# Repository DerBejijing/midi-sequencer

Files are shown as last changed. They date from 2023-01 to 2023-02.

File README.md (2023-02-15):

# midi-sequencer
midi sequencer firmware for raspberry pico (moog 960-sequencer inspired)  
Inspired by moog, but turned out to look more like the MAQ16 lul  

## about  
This is a midi step sequencer inspired by the 960 made by moog in the 70s.
Since getting to know it, I have always loved the moog IIIp modular synthesizer, which is why I decided to build my own version of the sequencer complement B.
The cabinet holds two of those modules plus an additional "half-height" (actually about 60%) row, like the original one.
During the building process, I diverged from my original design over and over again, and in the end, I even had to borrow some parts from the other sequencer in the cabinet.  

## features  
- 3 rows with eight steps  
- rows can be played in parallel or serial  
- the lengths of all rows can be adjusted independently  
- a variable amount of ratcheting can be set per step  
- speed is adjustable  
- all values are sent over midi (channels 0-3 in parallel mode, 0 in serial)  

<br/>

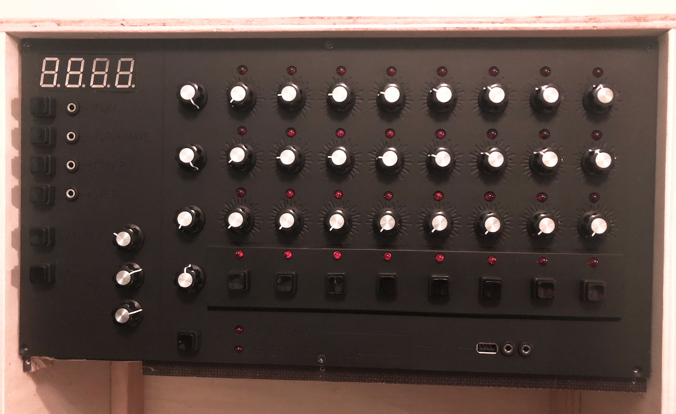
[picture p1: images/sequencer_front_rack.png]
  

TODO-List:  
---> add serial communication to controller  
---> find out how to make markdown add padding to a list next to an image >:(

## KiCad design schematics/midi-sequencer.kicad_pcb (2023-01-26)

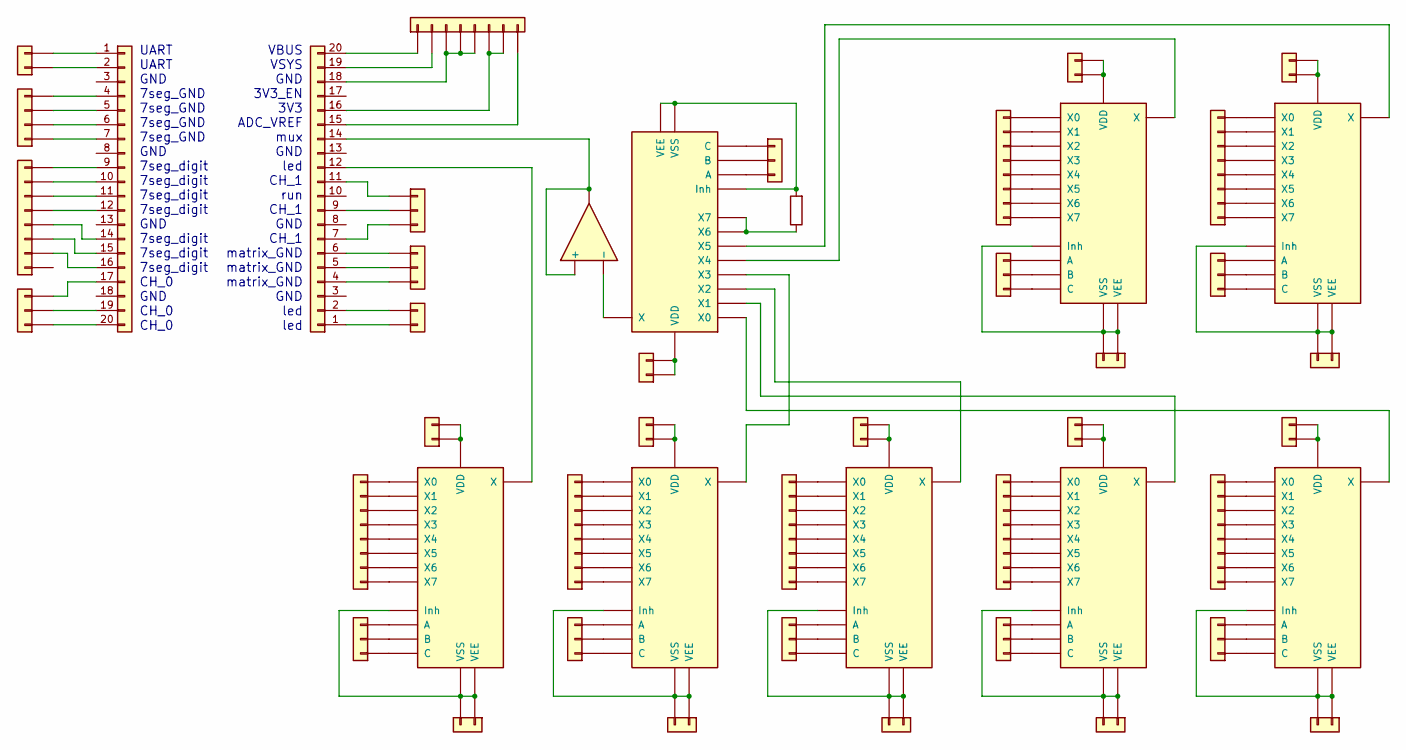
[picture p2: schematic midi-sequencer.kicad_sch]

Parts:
J1, J11, J12, J14, J17, J18, J19, J23, J24, J29, J30, J31, J32, J37, J38, J39, J40: Conn_01x02; PinHeader_1x02_P2.54mm_Vertical
J2: Conn_01x04; PinHeader_1x04_P2.54mm_Vertical
J3, J7, J13, J15, J21, J25, J27, J33, J35: Conn_01x08; PinHeader_1x08_P2.54mm_Vertical
J4, J8, J9, J10, J16, J20, J22, J26, J28, J34, J36: Conn_01x03; PinHeader_1x03_P2.54mm_Vertical
J5, J6: Conn_01x20; PinHeader_1x20_P2.54mm_Vertical
R1: R; R_Box_L13.0mm_W4.0mm_P9.00mm
U1, U3, U4, U5, U6, U7, U8, U9: 4051; DIP-16_W7.62mm_Socket
U2: OPA1622; DIP-14_W7.62mm_Socket

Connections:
unnamed: J1.1, J5.2
unnamed: J1.2, J5.1
unnamed: J2.1, J5.7
unnamed: J2.2, J5.6
unnamed: J2.3, J5.5
unnamed: J2.4, J5.4
unnamed: J3.2, J5.16
unnamed: J3.3, J5.15
unnamed: J3.4, J5.14
unnamed: J3.5, J5.12
unnamed: J3.6, J5.11
unnamed: J3.7, J5.10
unnamed: J3.8, J5.9
unnamed: J4.1, J5.20
unnamed: J4.2, J5.19
unnamed: J4.3, J5.17
unnamed: J6.7, J9.3
unnamed: J6.12, U1.3 (X)
unnamed: J7.1, U1.4 (X7)
unnamed: J7.2, U1.2 (X6)
unnamed: J7.3, U1.5 (X5)
unnamed: J7.4, U1.1 (X4)
unnamed: J7.5, U1.12 (X3)
unnamed: J7.6, U1.15 (X2)
unnamed: J7.7, U1.14 (X1)
unnamed: J7.8, U1.13 (X0)
unnamed: J8.1, U1.9 (C)
unnamed: J8.2, U1.10 (B)
unnamed: J8.3, U1.11 (A)
unnamed: J6.11, J9.1
unnamed: J6.9, J9.2
unnamed: J6.6, J10.1
unnamed: J6.5, J10.2
unnamed: J6.4, J10.3
unnamed: J6.2, J11.1
unnamed: J6.1, J11.2
unnamed: J12.1, J12.2, U1.16 (VDD)
unnamed: J6.20, J13.1
unnamed: J6.19, J13.2
unnamed: J6.18, J13.3, J13.4, J13.5
unnamed: J6.16, J13.6, J13.7
unnamed: J6.15, J13.8
unnamed: J14.1, J14.2, U1.6 (Inh), U1.7 (VEE), U1.8 (VSS)
unnamed: J15.1, U4.4 (X7)
unnamed: J15.2, U4.2 (X6)
unnamed: J15.3, U4.5 (X5)
unnamed: J15.4, U4.1 (X4)
unnamed: J15.5, U4.12 (X3)
unnamed: J15.6, U4.15 (X2)
unnamed: J15.7, U4.14 (X1)
unnamed: J15.8, U4.13 (X0)
unnamed: J16.1, U4.9 (C)
unnamed: J16.2, U4.10 (B)
unnamed: J16.3, U4.11 (A)
unnamed: J17.1, J17.2, U3.16 (VDD)
unnamed: J18.1, J18.2, U4.16 (VDD)
unnamed: J19.1, J19.2, U4.6 (Inh), U4.7 (VEE), U4.8 (VSS)
unnamed: J20.1, U3.9 (C)
unnamed: J20.2, U3.10 (B)
unnamed: J20.3, U3.11 (A)
unnamed: J21.1, U5.4 (X7)
unnamed: J21.2, U5.2 (X6)
unnamed: J21.3, U5.5 (X5)
unnamed: J21.4, U5.1 (X4)
unnamed: J21.5, U5.12 (X3)
unnamed: J21.6, U5.15 (X2)
unnamed: J21.7, U5.14 (X1)
unnamed: J21.8, U5.13 (X0)
unnamed: J22.1, U5.9 (C)
unnamed: J22.2, U5.10 (B)
unnamed: J22.3, U5.11 (A)
unnamed: J23.1, J23.2, U5.16 (VDD)
unnamed: J24.1, J24.2, U5.6 (Inh), U5.7 (VEE), U5.8 (VSS)
unnamed: J25.1, U6.4 (X7)
unnamed: J25.2, U6.2 (X6)
unnamed: J25.3, U6.5 (X5)
unnamed: J25.4, U6.1 (X4)
unnamed: J25.5, U6.12 (X3)
unnamed: J25.6, U6.15 (X2)
unnamed: J25.7, U6.14 (X1)
unnamed: J25.8, U6.13 (X0)
unnamed: J26.1, U6.9 (C)
unnamed: J26.2, U6.10 (B)
unnamed: J26.3, U6.11 (A)
unnamed: J27.1, U7.4 (X7)
unnamed: J27.2, U7.2 (X6)
unnamed: J27.3, U7.5 (X5)
unnamed: J27.4, U7.1 (X4)
unnamed: J27.5, U7.12 (X3)
unnamed: J27.6, U7.15 (X2)
unnamed: J27.7, U7.14 (X1)
unnamed: J27.8, U7.13 (X0)
unnamed: J28.1, U7.9 (C)
unnamed: J28.2, U7.10 (B)
unnamed: J28.3, U7.11 (A)
unnamed: J29.1, J29.2, U6.16 (VDD)
unnamed: J30.1, J30.2, U7.16 (VDD)
unnamed: J31.1, J31.2, U6.6 (Inh), U6.7 (VEE), U6.8 (VSS)
unnamed: J32.1, J32.2, U7.6 (Inh), U7.7 (VEE), U7.8 (VSS)
unnamed: J33.1, U8.4 (X7)
unnamed: J33.2, U8.2 (X6)
unnamed: J33.3, U8.5 (X5)
unnamed: J33.4, U8.1 (X4)
unnamed: J33.5, U8.12 (X3)
unnamed: J33.6, U8.15 (X2)
unnamed: J33.7, U8.14 (X1)
unnamed: J33.8, U8.13 (X0)
unnamed: J34.1, U8.9 (C)
unnamed: J34.2, U8.10 (B)
unnamed: J34.3, U8.11 (A)
unnamed: J35.1, U9.4 (X7)
unnamed: J35.2, U9.2 (X6)
unnamed: J35.3, U9.5 (X5)
unnamed: J35.4, U9.1 (X4)
unnamed: J35.5, U9.12 (X3)
unnamed: J35.6, U9.15 (X2)
unnamed: J35.7, U9.14 (X1)
unnamed: J35.8, U9.13 (X0)
unnamed: J36.1, U9.9 (C)
unnamed: J36.2, U9.10 (B)
unnamed: J36.3, U9.11 (A)
unnamed: J37.1, J37.2, U8.16 (VDD)
unnamed: J38.1, J38.2, U9.16 (VDD)
unnamed: J39.1, J39.2, U8.6 (Inh), U8.7 (VEE), U8.8 (VSS)
unnamed: J40.1, J40.2, U9.6 (Inh), U9.7 (VEE), U9.8 (VSS)
unnamed: R1.1, U3.2 (X6), U3.4 (X7)
unnamed 126: U2.4 (V-), U2.11 (V-); also elsewhere on the board
unnamed: U3.1 (X4), U6.3 (X)
unnamed: U3.5 (X5), U8.3 (X)
unnamed: U3.12 (X3), U4.3 (X)
unnamed: U3.13 (X0), U9.3 (X)
unnamed: U3.14 (X1), U7.3 (X)
unnamed: U3.15 (X2), U5.3 (X)

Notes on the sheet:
UART UART GND 7seg_GND 7seg_GND 7seg_GND 7seg_GND GND 7seg_digit 7seg_digit 7seg_digit 7seg_digit GND 7seg_digit 7seg_digit 7seg_digit CH_0 GND CH_0 CH_0
VBUS VSYS GND 3V3_EN 3V3 ADC_VREF mux GND led CH_1 run CH_1 GND CH_1 matrix_GND matrix_GND matrix_GND GND led led

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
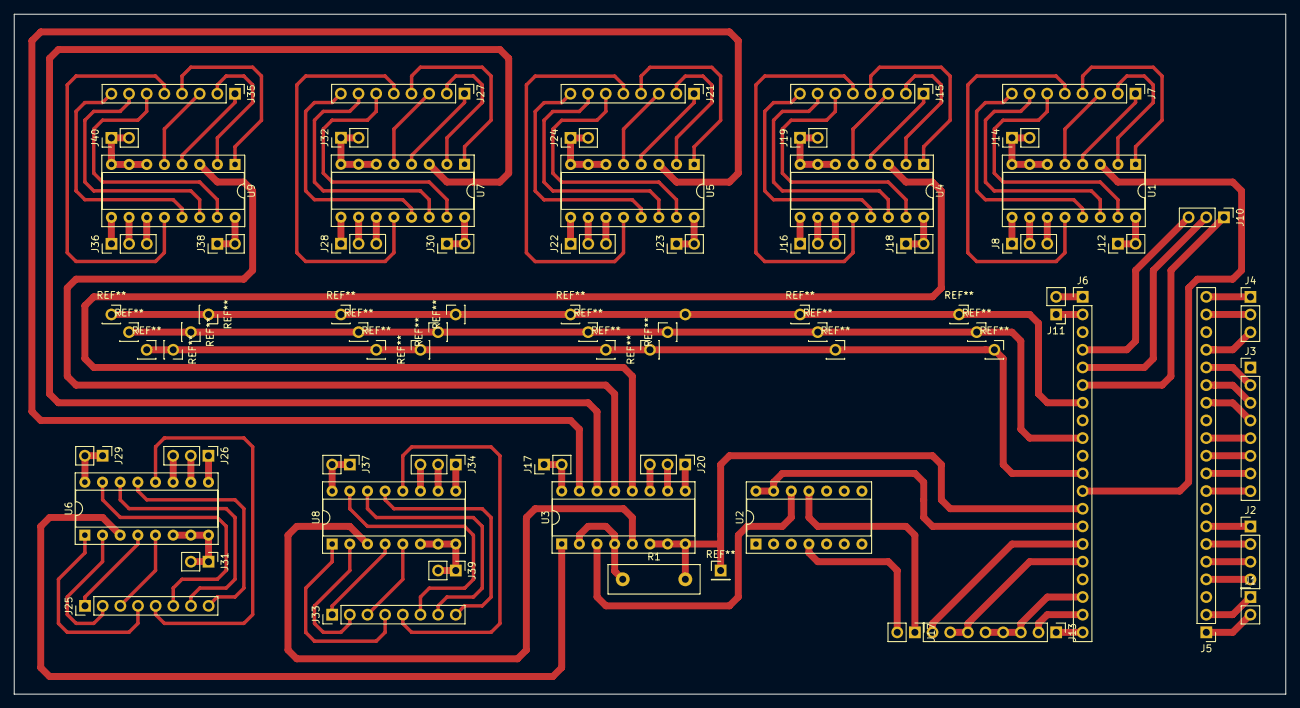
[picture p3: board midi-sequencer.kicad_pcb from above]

Board: 2 copper layers, 182.9 x 97.8 mm, 50 parts (0 on the bottom side), 132 nets.

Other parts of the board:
J17#2: Conn_01x02; PinHeader_1x02_P2.54mm_Vertical

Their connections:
unnamed 126: J17#2.2; also elsewhere on the board

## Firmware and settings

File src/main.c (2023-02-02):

#include <stdio.h>
#include "pico/stdlib.h"
#include "pico/binary_info.h"
#include "hardware/timer.h"
#include "hardware/gpio.h"
#include "hardware/adc.h"

#include "../include/seq_globals.h"
#include "../include/seq_gpio.h"
#include "../include/seq_interface.h"
#include "../include/seq_sequencer.h"
#include "../include/seq_seven_segment.h"

#include "bsp/board.h"
#include "tusb.h"

int main() {
    stdio_init_all();

    board_init();
    tusb_init();

    //sleep_ms(5000);

    // initialize all modules
    seq_gpio_init();
    seq_interface_init();
    seq_seven_segment_init();
    sequencer_init();

    // register callbacks
    seq_gpio_register_callback(0, 0, 1, sequencer_toggle_running);
    seq_gpio_register_callback(0, 6, 0, sequencer_toggle_joined);
    seq_gpio_register_callback(0, 1, 1, sequencer_terminate);

    // set illumination time of 7 segment display
    seq_seven_segment_time(500000);

    // store time of last refresh event
    uint64_t last_refresh_v = 0;
    uint64_t last_refresh_s = 0;

    // create a list of all available BPM choices
    uint16_t bpm_choices[25] = {0};
    for(uint8_t i = 0; i < 25; ++i) bpm_choices[i] = 60 + 20 * i;

    /*// create a list of all available BPM choices with fine tuning
    uint16_t bpm_choices_list[25][25] = {0};
    for(uint8_t x = 0; x < 25; ++x) for(uint8_t y = 0; y < 25; ++y) bpm_choices_list[x][y] = (x * 60) + (y * 5);*/


    while(1) {
        uint64_t current_time = time_us_64();

        tud_task();

        // tick all essential modules
        seq_gpio_tick();
        sequencer_tick();


        // refresh all analog values
        if(current_time > last_refresh_v + REFRESH_VALUES_US) {
            last_refresh_v = current_time;

            // update interface
            seq_interface_tick();
            seq_interface_stage_select(seq_gpio_read_setting(3));
            seq_interface_stage_set(seq_gpio_read_setting(4));

            // set bpm
            sequencer_set_bpm(bpm_choices[seq_gpio_read_setting(6)]);

            // update all values specific for a row/step
            for(uint8_t row = 0; row < SEQ_ROWS; ++row) {
                for(uint8_t stage = 0; stage < SEQ_STAGES; ++stage) sequencer_set_value(row * SEQ_STAGES + stage, seq_gpio_read_value(row, stage));
                sequencer_set_stages(row, seq_gpio_read_setting(row));
            }
        }


        // update seven segment display
        if(current_time > last_refresh_s + REFRESH_SEVEN_SEGMENT_US) {
            last_refresh_s = current_time;
            seq_seven_segment_tick();
        }
    }

    return 0;
}

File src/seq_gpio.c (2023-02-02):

#include "../include/seq_gpio.h"
#include <stdio.h>

#define INDEX_REVERSE(i) SEQ_STAGES - 1 - i

#define ADC_RANGE (1 << 12)
#define ADC_CONV_24 (24.0 / (ADC_RANGE - 1))
#define ADC_CONV_8 (8.0 / (ADC_RANGE - 1))

#define MATRIX_GND_0 18
#define MATRIX_GND_1 19
#define MATRIX_GND_2 20

#define MATRIX_PWR 27

#define MUX_CH_A 26
#define MUX_CH_B 22
#define MUX_CH_C 21

#define MAIN_MUX_CH_A 15
#define MAIN_MUX_CH_B 14
#define MAIN_MUX_CH_C 13

#define MAIN_MUX_READ 28

#define ADDR_ROW_0 0
#define ADDR_ROW_1 1
#define ADDR_ROW_2 5
#define ADDR_ROW_3 4
#define ADDR_SETTINGS 2
#define ADDR_BUTTONS 3

#define LED_SERIAL 0
#define LED_PARALLEL 1 

#define SETTINGS_BUTTONS 7
#define SETTINGS_VALUES 7


// struct to store and debounce analog values
struct analog_reading {
    uint8_t value;              // last value that was certain
    uint8_t value_new;          // recently measured but invalidated value
    uint8_t error;              // how heavily the value is fluctuating
    uint8_t certainty;          // number of equal readings in series
};

// struct to store callbacks
struct callback {
    void (*callback)();         // function pointer to callback function
    uint8_t is_interface;       // whether or not the button belongs to the interface row
    uint8_t button;             // id of the button
    uint8_t momentary;          // push button or latching button
    uint8_t state;              // current state of the button
};


// arrays to store all debounce structs
struct analog_reading sg_values_stages[SEQ_ROWS * SEQ_STAGES];
struct analog_reading sg_values_settings[SETTINGS_BUTTONS];


// array to store all callbacks
struct callback sg_button_callback[SETTINGS_BUTTONS + SEQ_STAGES];


// array to store all values for settings and interface row
uint8_t sg_values_interface[SEQ_STAGES];
uint8_t sg_values_buttons[SETTINGS_BUTTONS];


// array to store all stages to be lit
uint8_t sg_matrix[SEQ_ROWS] = {0};


// how many times the matrix will be re-rendered per tick
uint8_t sg_matrix_cycles = 1;

// how many times buttons will be re-read before being trusted
uint8_t sg_debounce_cycles = 1;


// delay in microseconds between different readings
uint64_t sg_buttons_read_delay = 1000;
uint64_t sg_settings_read_delay = 2000;
uint64_t sg_values_read_delay = 1000;

// store time of last refresh event
uint64_t sg_buttons_read_last = 0;
uint64_t sg_settings_read_last = 0;
uint64_t sg_values_read_last = 0;



/* initialize gpio */
void seq_gpio_init(void) {
    sg_matrix_cycles = 1;
    sg_debounce_cycles = 1;

    gpio_init(MATRIX_GND_0);
    gpio_set_dir(MATRIX_GND_0, GPIO_OUT);
    gpio_init(MATRIX_GND_1);
    gpio_set_dir(MATRIX_GND_1, GPIO_OUT);
    gpio_init(MATRIX_GND_2);
    gpio_set_dir(MATRIX_GND_2, GPIO_OUT);

    gpio_init(MATRIX_PWR);
    gpio_set_dir(MATRIX_PWR, GPIO_OUT);

    gpio_init(MUX_CH_A);
    gpio_set_dir(MUX_CH_A, GPIO_OUT);
    gpio_init(MUX_CH_B);
    gpio_set_dir(MUX_CH_B, GPIO_OUT);
    gpio_init(MUX_CH_C);
    gpio_set_dir(MUX_CH_C, GPIO_OUT);

    gpio_init(MAIN_MUX_CH_A);
    gpio_set_dir(MAIN_MUX_CH_A, GPIO_OUT);
    gpio_init(MAIN_MUX_CH_B);
    gpio_set_dir(MAIN_MUX_CH_B, GPIO_OUT);
    gpio_init(MAIN_MUX_CH_C);
    gpio_set_dir(MAIN_MUX_CH_C, GPIO_OUT);

    gpio_init(LED_SERIAL);
    gpio_set_dir(LED_SERIAL, GPIO_OUT);
    gpio_init(LED_PARALLEL);
    gpio_set_dir(LED_PARALLEL, GPIO_OUT);

    adc_init();
    adc_gpio_init(MAIN_MUX_READ);
    adc_select_input(2);

    // set all callback pointers to seq_gpio_callback_void(void)
    for(uint8_t i = 0; i < SEQ_STAGES + SETTINGS_BUTTONS; ++i) sg_button_callback[i].callback = seq_gpio_callback_void;
    
    // initialize the interface row
    // this is necessary, because it uses latching buttons
    gpio_put(MAIN_MUX_CH_A, ADDR_ROW_3 >> 0 & 1);
    gpio_put(MAIN_MUX_CH_B, ADDR_ROW_3 >> 1 & 1);
    gpio_put(MAIN_MUX_CH_C, ADDR_ROW_3 >> 2 & 1);

    for(uint8_t i = 0; i < SEQ_STAGES; ++i) {
        gpio_put(MUX_CH_A, i >> 0 & 1);
        gpio_put(MUX_CH_B, i >> 1 & 1);
        gpio_put(MUX_CH_C, i >> 2 & 1);

        sg_values_interface[i] = adc_read() > (ADC_CONV_24 * ADC_RANGE / 2);
    }
}


/* update the gpio */
void seq_gpio_tick(void) {
    uint64_t current_time = time_us_64();

    // update all buttons
    if(current_time > sg_buttons_read_last + sg_buttons_read_delay) {
        sg_buttons_read_last = current_time;
        seq_gpio_tick_buttons();
    }

    // update settings
    if(current_time > sg_settings_read_last + sg_settings_read_delay) {
        sg_settings_read_last = current_time;
        seq_gpio_tick_settings();
    }

    // update stages
    if(current_time > sg_values_read_last + sg_values_read_delay) {
        sg_values_read_last = current_time;
        seq_gpio_tick_values();
    }

    // update the led matrix
    seq_gpio_matrix_tick();
}
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

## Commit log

2023-01-11 reading buttons
2023-01-12 very evil function pointers to ? fixed
    [main.c, seq_gpio.c, seq_sequencer.c]
2023-01-12 fix sequencer tick function
    [main.c, seq_gpio.c, seq_sequencer.c]
2023-01-12 no longer skipping first stages
    [seq_sequencer.c]
2023-01-12 cleaning up and fixing some issues
    [main.c, seq_gpio.c, seq_sequencer.c]
2023-01-14 fixed issues with seven segment display
    [main.c, seq_gpio.c, seq_seven_segment.c]
2023-01-14 add indicator led support for serial/parallel mode
2023-01-26 add schematics
    [midi-sequencer.kicad_pcb, midi-sequencer.kicad_sch]
2023-01-29 fixed incorrect behavior in serial mode
    [main.c, seq_gpio.c, seq_interface.c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]
2023-01-29 unless I redo the wiring...
